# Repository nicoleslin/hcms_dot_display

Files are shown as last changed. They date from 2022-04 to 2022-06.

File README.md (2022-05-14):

# hcms_dot_display
repo for board files and drivers for hp hcms dot displays

## link dump
https://github.com/SpenceKonde/megaTinyCore/blob/master/megaavr/extras/ATtiny_x26.md
https://teddywarner.org/Projects/SerialUPDI/
https://github.com/SpenceKonde/AVR-Guidance/blob/master/UPDI/jtag2updi.md
http://ad7i.net/main/analysis-of-resistor-values-for-pymcuprog-usbusart-serial-programming/
https://www.mouser.com/ProductDetail/Apem/MHPS2283?qs=%2Fs1LKTamv0woxsbKv1Ncmw%3D%3D

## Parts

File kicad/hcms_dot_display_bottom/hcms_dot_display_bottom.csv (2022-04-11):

Source: | C:\Users\nslni\Documents\projects\dot_display\hcms_dot_display\kicad\hcms_dot_display\hcms_dot_display.kicad_sch
Date: | 04/10/2022 08:59:22
Tool: | Eeschema (6.0.2)
Generator: | C:\Users\nslni\Documents\KiCad\6.0\scripting\plugins/bom_csv_grouped_by_value_with_fp_and_mpn.py
Component Count: | 52
Ref | Qnty | Value | Cmp name | Footprint | Description | Vendor | MPN
C1, C9, C10, C11, | 4 | 10nF | C_Small | Capacitor_SMD:C_0603_1608Metric | Unpolarized capacitor, small symbol
C2, C3, C6, C8, C12, | 5 | 100nF | C_Small | Capacitor_SMD:C_0603_1608Metric | Unpolarized capacitor, small symbol
C4, C5, | 2 | 47pF | C_Small | Capacitor_SMD:C_0603_1608Metric | Unpolarized capacitor, small symbol
C7, | 1 | 4.7uF | C_Small | Capacitor_SMD:C_0603_1608Metric | Unpolarized capacitor, small symbol
D1, | 1 | HCMS-272X | HCMS-272X | hcms:HCMS-2722 |  |  | HCMS-2722
J1, J3, | 2 | Conn_01x12 | Conn_01x12 | hcms:board to board con top bot | Generic connector, single row, 01x12, script generated (kicad-library-utils/schlib/autogen/connector/)
J2, | 1 | USB_C_Receptacle_USB2.0 | USB_C_Receptacle_USB2.0 | hcms:213716-0001 | USB 2.0-only Type-C Receptacle connector |  | 213716-0001
J4, | 1 | Conn_01x11_Female | Conn_01x11_Female | Connector_PinSocket_2.54mm:PinSocket_1x11_P2.54mm_Vertical | Generic connector, single row, 01x11, script generated (kicad-library-utils/schlib/autogen/connector/)
J5, | 1 | Conn_01x11_Male | Conn_01x11_Male | Connector_PinHeader_2.54mm:PinHeader_1x11_P2.54mm_Vertical | Generic connector, single row, 01x11, script generated (kicad-library-utils/schlib/autogen/connector/)
J6, J7, | 2 | Conn_01x12 | Conn_01x12 | hcms:board to board con left right | Generic connector, single row, 01x12, script generated (kicad-library-utils/schlib/autogen/connector/)
Q1, Q2, Q3, Q4, Q5, | 5 | Q_PMOS_DSG | Q_PMOS_DSG | Package_TO_SOT_SMD:SOT-23 | P-MOSFET transistor, drain/source/gate |  | DMP3099L-13
Q6, | 1 | Q_PMOS_DSG | SI4425FDY | Package_SO:SO-8_5.3x6.2mm_P1.27mm | P-Channel 30 V 12.7A (Ta), 18.3A (Tc) 2.3W (Ta), 4.8W (Tc) Surface Mount 8-SOIC |  | SI4425FDY-T1-GE3
R1, R6, R21, R22, | 4 | 0 | R | Resistor_SMD:R_0603_1608Metric | Resistor
R2, R7, R16, R17, | 4 | DNP | R | Resistor_SMD:R_0603_1608Metric | Resistor
R3, R10, R11, R12, R13, R14, | 6 | 200 | R | Resistor_SMD:R_0603_1608Metric | Resistor
R4, R5, | 2 | 5.1k | R | Resistor_SMD:R_0603_1608Metric | Resistor
R8, R9, | 2 | 27 | R | Resistor_SMD:R_0603_1608Metric | Resistor
R15, | 1 | 1k | R | Resistor_SMD:R_0603_1608Metric | Resistor
R18, R19, R20, | 3 | 10k | R | Resistor_SMD:R_0603_1608Metric | Resistor
RV1, | 1 | R_Potentiometer | R_Potentiometer | hcms:TRIM_3352T-1-201LF | Potentiometer |  | 3352T-1-503LF
SW1, | 1 | SW_DIP_x03 | SW_DIP_x03 | hcms:BPA03SB | 3x DIP Switch, Single Pole Single Throw (SPST) switch, small symbol |  | BPA03SB
U1, | 1 | ATtiny826-SXX | ATtiny826-SXX | Package_SO:SOIC-20W_7.5x12.8mm_P1.27mm | 20MHz, 8kB Flash, 512B SRAM, 512B EEPROM, debugWIRE, SOIC-20 |  | ATTINY826-SFR
U2, | 1 | FT231XS | FT231XS | Package_SO:SSOP-20_3.9x8.7mm_P0.635mm | Full Speed USB to Full Handshake UART, SSOP-20 |  | FT231XS-U

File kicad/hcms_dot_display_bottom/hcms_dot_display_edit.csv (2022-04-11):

Source: | C:\Users\nslni\Documents\projects\dot_display\hcms_dot_display\kicad\hcms_dot_display\hcms_dot_display.kicad_sch
Date: | 04/10/2022 08:59:22
Tool: | Eeschema (6.0.2)
Generator: | C:\Users\nslni\Documents\KiCad\6.0\scripting\plugins/bom_csv_grouped_by_value_with_fp_and_mpn.py
Component Count: | 52
baselining qty for 5 control boards (3 yield + attrition), 10 display boards (6 yield + attrition + min price break)
passives for 15 boards
Ref | Qnty | Value | Cmp name | Footprint | Description | Vendor | MPN | deviation | Qty in cart
C1, C9, C10, C11, | 4 | 10nF | C_Small | Capacitor_SMD:C_0603_1608Metric | Unpolarized capacitor, small symbol |  | 06033C103JAT4A |  | 60
C2, C3, C6, C8, C12, | 5 | 100nF | C_Small | Capacitor_SMD:C_0603_1608Metric | Unpolarized capacitor, small symbol |  | C0603C104K3RAC7081 |  | 100
C4, C5, | 2 | 47pF | C_Small | Capacitor_SMD:C_0603_1608Metric | Unpolarized capacitor, small symbol |  | 06033C470KAT2A |  | 50
C7, | 1 | 4.7uF | C_Small | Capacitor_SMD:C_0603_1608Metric | Unpolarized capacitor, small symbol |  | GRM188C71C475KE21D |  | 15
D1, | 1 | HCMS-272X | HCMS-272X | hcms:HCMS-2722 |  |  | HCMS-2722 |  | N/A
J1, J3, | 2 | Conn_01x12 | Conn_01x12 | hcms:board to board con top bot | Generic connector, single row, 01x12, script generated (kicad-library-utils/schlib/autogen/connector/) |  |  |  | N/A
J2, | 1 | USB_C_Receptacle_USB2.0 | USB_C_Receptacle_USB2.0 | hcms:213716-0001 | USB 2.0-only Type-C Receptacle connector |  | 213716-0001
J4, | 1 | Conn_01x11_Female | Conn_01x11_Female | Connector_PinSocket_2.54mm:PinSocket_1x11_P2.54mm_Vertical | Generic connector, single row, 01x11, script generated (kicad-library-utils/schlib/autogen/connector/) |  | SMC-1-11-1-GT |  | 5
J5, | 1 | Conn_01x11_Male | Conn_01x11_Male | Connector_PinHeader_2.54mm:PinHeader_1x11_P2.54mm_Vertical | Generic connector, single row, 01x11, script generated (kicad-library-utils/schlib/autogen/connector/) |  | PH1-11-UA |  | 10
J6, J7, | 2 | Conn_01x12 | Conn_01x12 | hcms:board to board con left right | Generic connector, single row, 01x12, script generated (kicad-library-utils/schlib/autogen/connector/) |  |  |  | N/A
Q1, Q2, Q3, Q4, Q5, | 5 | Q_PMOS_DSG | Q_PMOS_DSG | Package_TO_SOT_SMD:SOT-23 | P-MOSFET transistor, drain/source/gate |  | DMP3099L-13 | PJA3411_R1_00001 | 50
Q6, | 1 | Q_PMOS_DSG | SI4425FDY | Package_SO:SO-8_5.3x6.2mm_P1.27mm | P-Channel 30 V 12.7A (Ta), 18.3A (Tc) 2.3W (Ta), 4.8W (Tc) Surface Mount 8-SOIC |  | SI4425FDY-T1-GE3 |  | 5
R1, R6, R21, R22, | 4 | 0 | R | Resistor_SMD:R_0603_1608Metric | Resistor |  | AC0603JR-070RL |  | 100
R2, R7, R16, R17, | 4 | DNP | R | Resistor_SMD:R_0603_1608Metric | Resistor |  |  |  | N/A
R3, R10, R11, R12, R13, R14, | 6 | 200 | R | Resistor_SMD:R_0603_1608Metric | Resistor |  | RNCP0603FTD200R |  | 100
R4, R5, | 2 | 5.1k | R | Resistor_SMD:R_0603_1608Metric | Resistor |  | RMCF0603FT5K10 |  | 30
R8, R9, | 2 | 27 | R | Resistor_SMD:R_0603_1608Metric | Resistor |  | RMCF0603FT27R0 |  | 30
R15, | 1 | 1k | R | Resistor_SMD:R_0603_1608Metric | Resistor |  | RMCF0603FT1K00 |  | 15
R18, R19, R20, | 3 | 10k | R | Resistor_SMD:R_0603_1608Metric | Resistor |  | RMCF0603FT10K0 |  | 100
RV1, | 1 | R_Potentiometer | R_Potentiometer | hcms:TRIM_3352T-1-201LF | Potentiometer |  | 3352T-1-503LF |  | 5
SW1, | 1 | SW_DIP_x03 | SW_DIP_x03 | hcms:BPA03SB | 3x DIP Switch, Single Pole Single Throw (SPST) switch, small symbol |  | BPA03SB |  | 5
U1, | 1 | ATtiny826-SXX | ATtiny826-SXX | Package_SO:SOIC-20W_7.5x12.8mm_P1.27mm | 20MHz, 8kB Flash, 512B SRAM, 512B EEPROM, debugWIRE, SOIC-20 |  | ATTINY826-SFR | ATTINY826-SF | 10
U2, | 1 | FT231XS | FT231XS | Package_SO:SSOP-20_3.9x8.7mm_P0.635mm | Full Speed USB to Full Handshake UART, SSOP-20 |  | FT231XS-U |  | 5

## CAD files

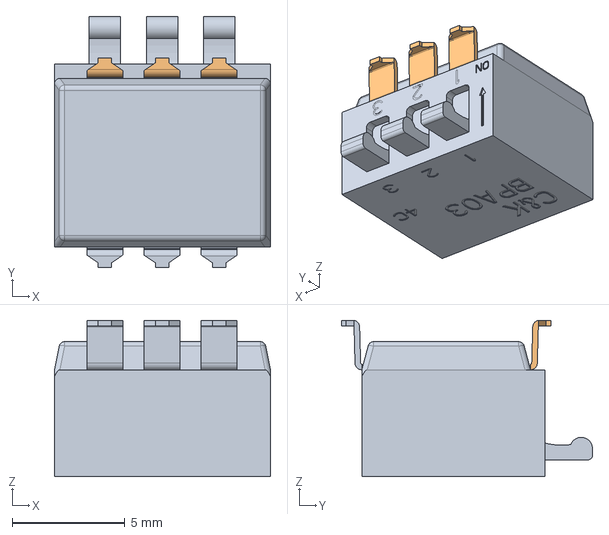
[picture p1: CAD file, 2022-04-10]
step/BPA03SB.stp
9.60 x 11.1 x 6.95 mm

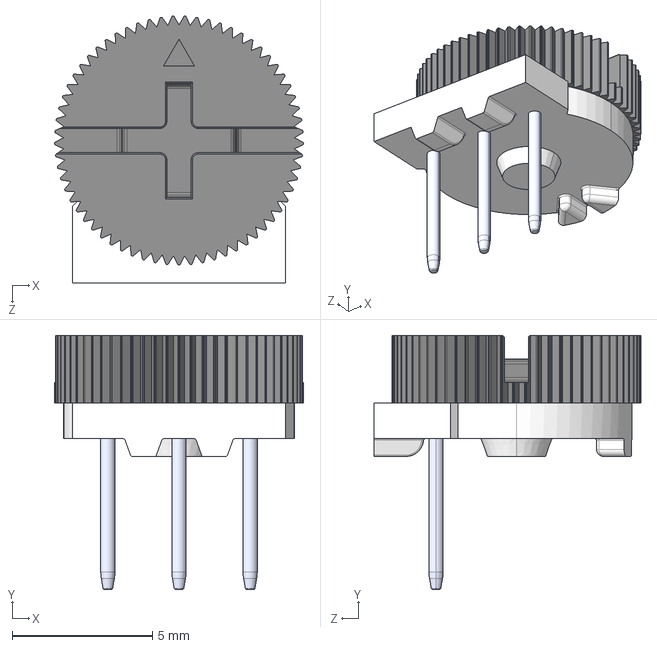
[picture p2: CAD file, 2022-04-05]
step/TRIM_3352T-1-201LF.step
8.89 x 9.07 x 9.52 mm

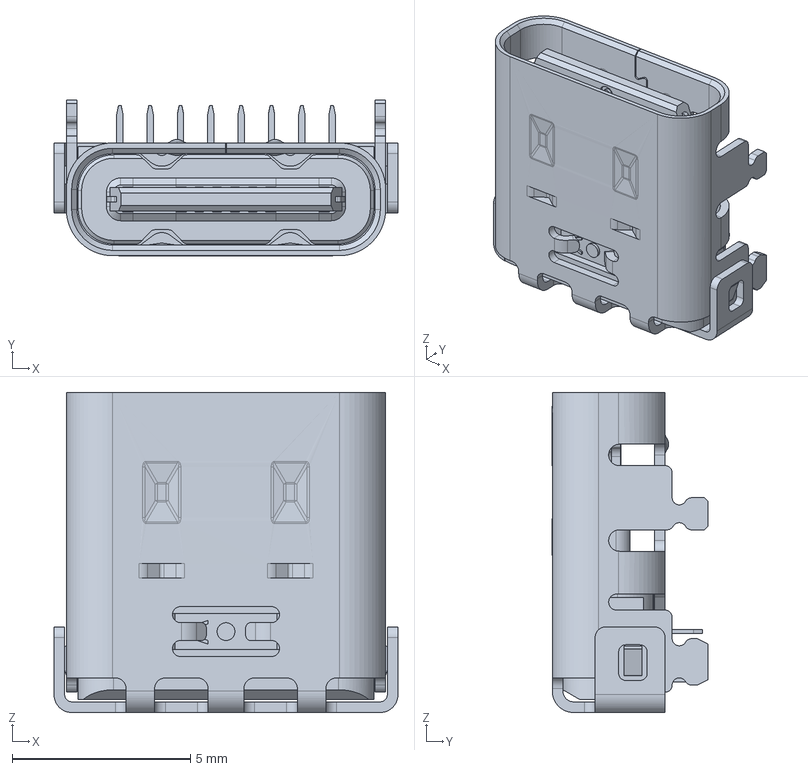
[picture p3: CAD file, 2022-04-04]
step/2137160001.stp
9.64 x 4.36 x 8.97 mm

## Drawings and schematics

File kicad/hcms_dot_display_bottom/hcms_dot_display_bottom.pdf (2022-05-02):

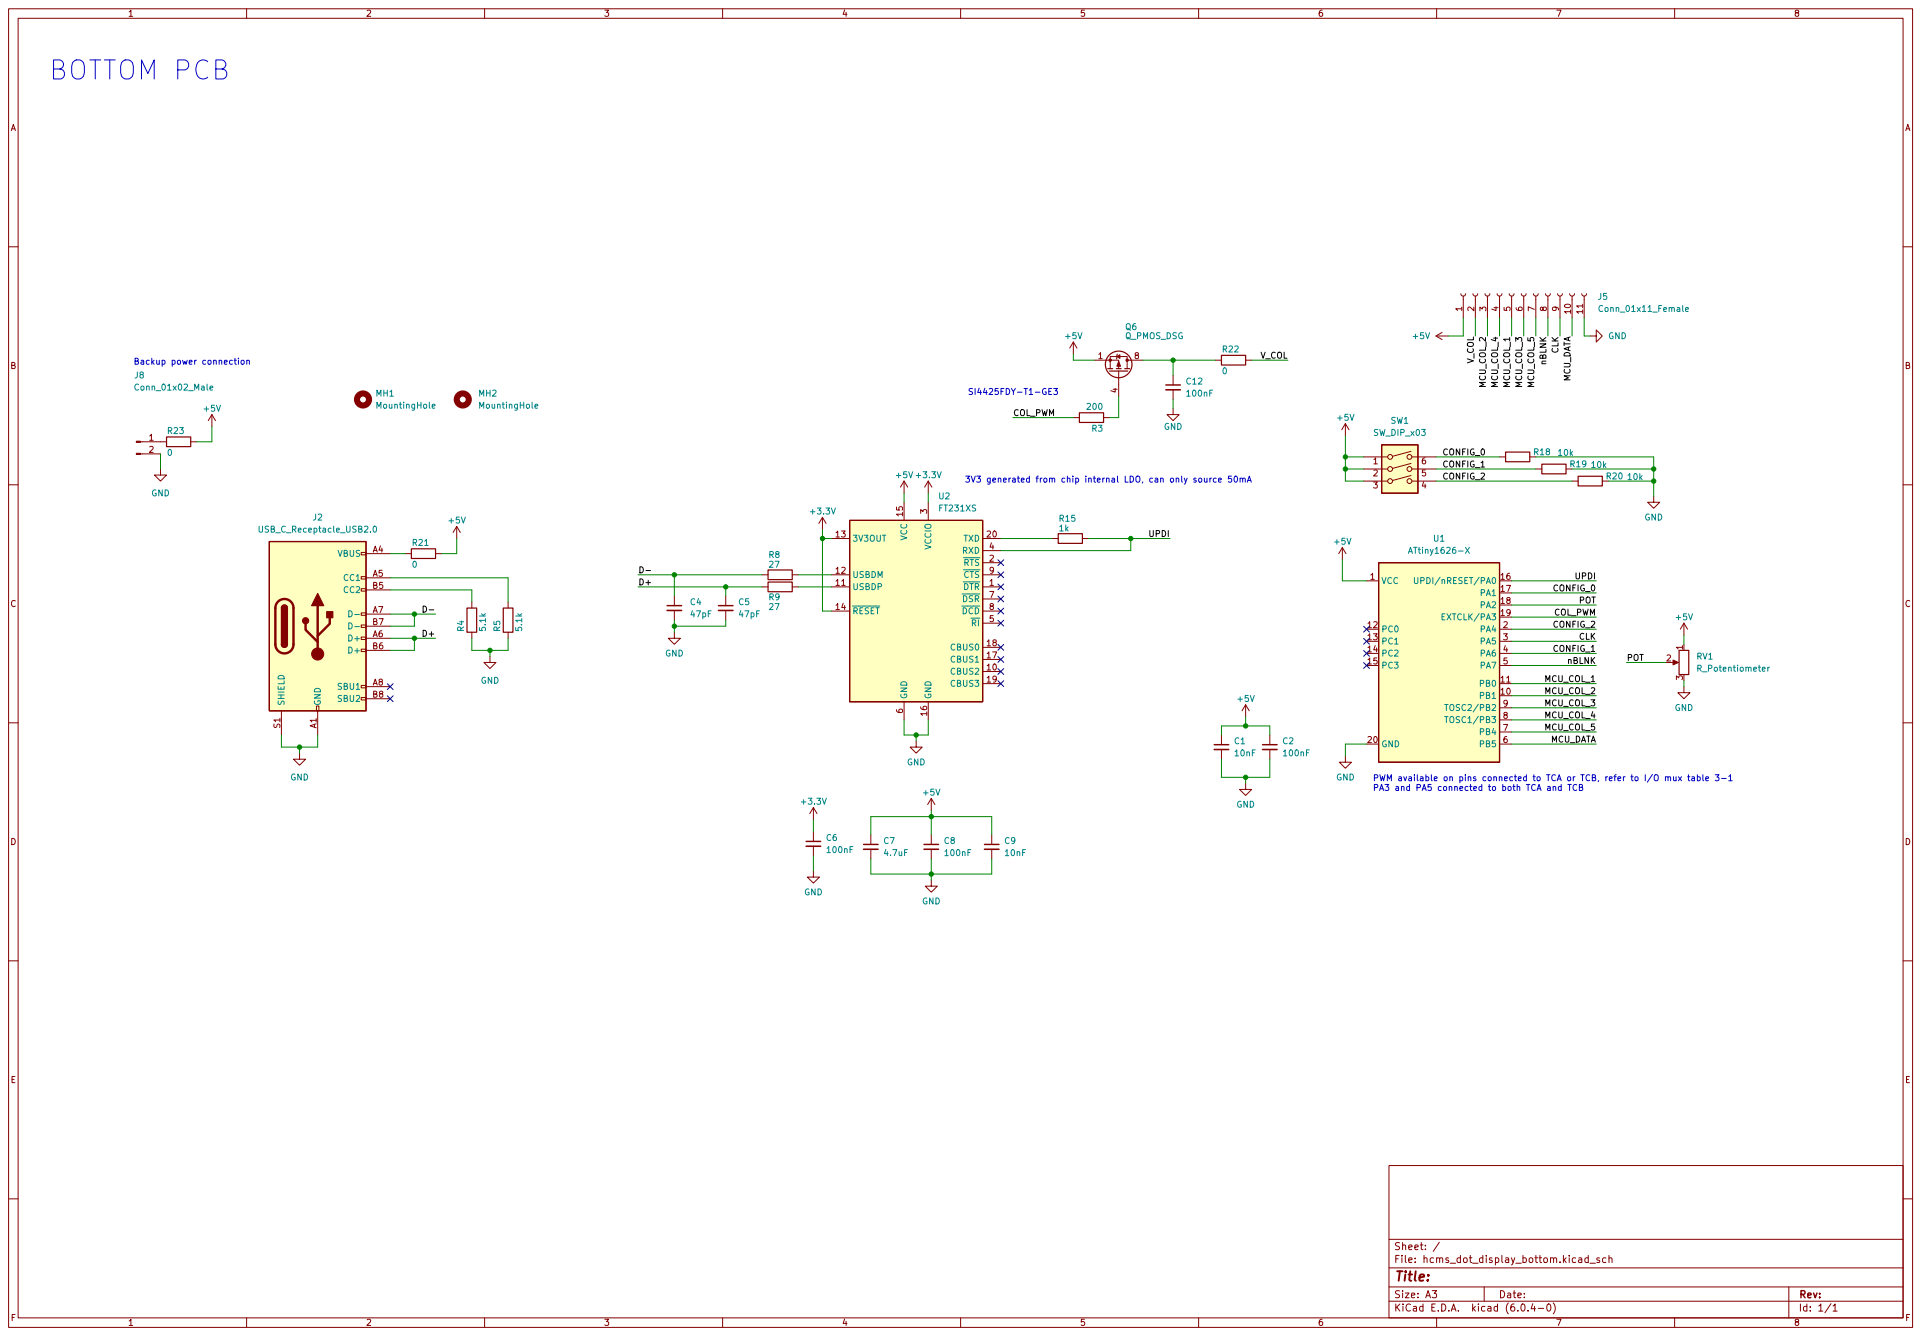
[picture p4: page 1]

6 ~{DSR} 7 ~{DCD} 8 ~{CTS} 9 U2FT231XS GND GND MH2 MountingHole MH1 MountingHole +5V +3.3V R19 10k R20 10k R21

3V3 generated from chip internal LDO, can only source 50mA

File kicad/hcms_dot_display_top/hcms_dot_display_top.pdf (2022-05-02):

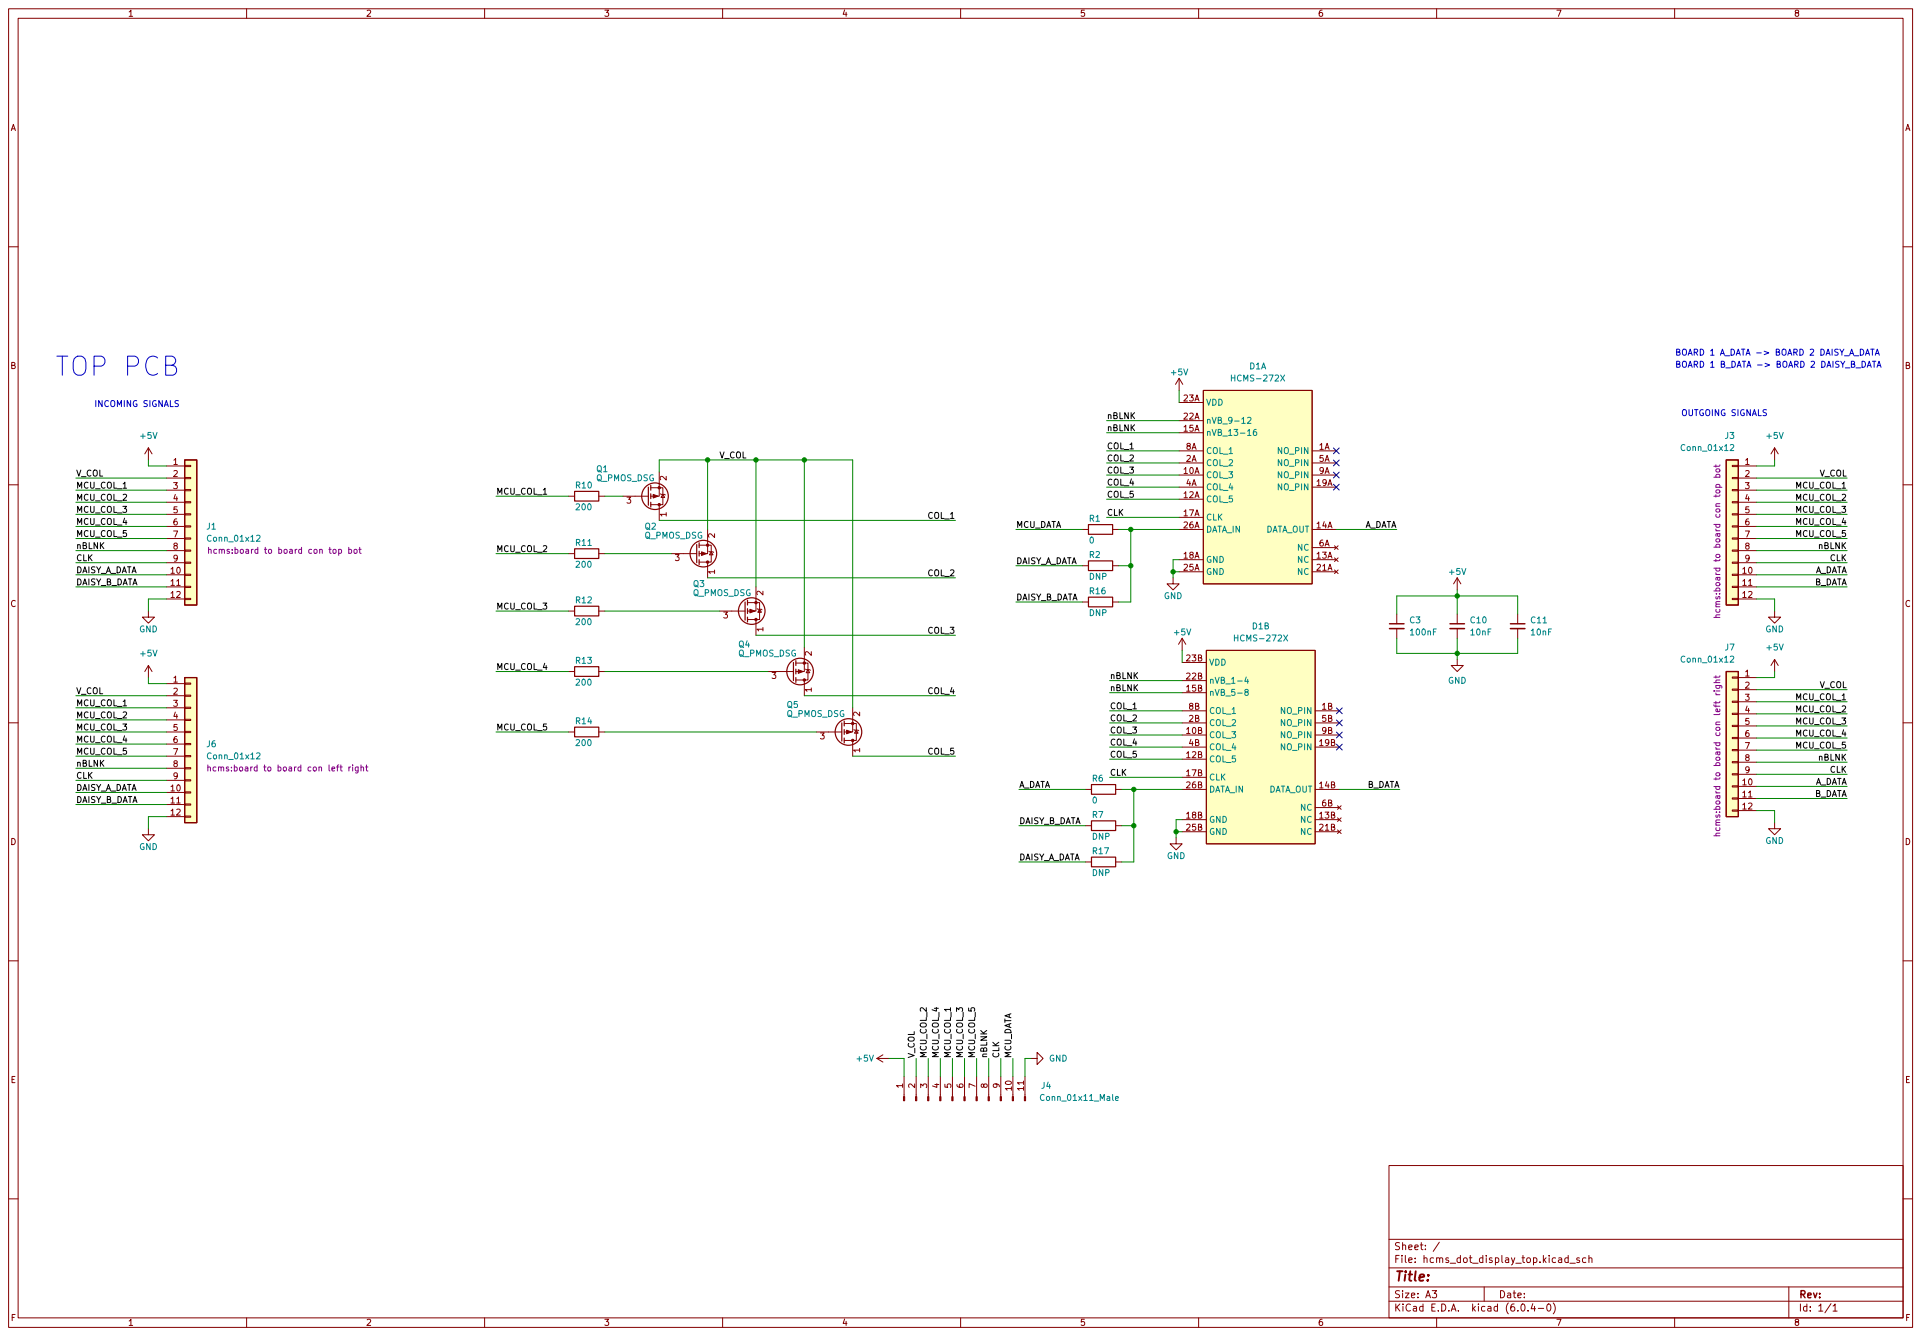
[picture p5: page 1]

INCOMING SIGNALS TOP PCB

hcms:board to board con left right GND

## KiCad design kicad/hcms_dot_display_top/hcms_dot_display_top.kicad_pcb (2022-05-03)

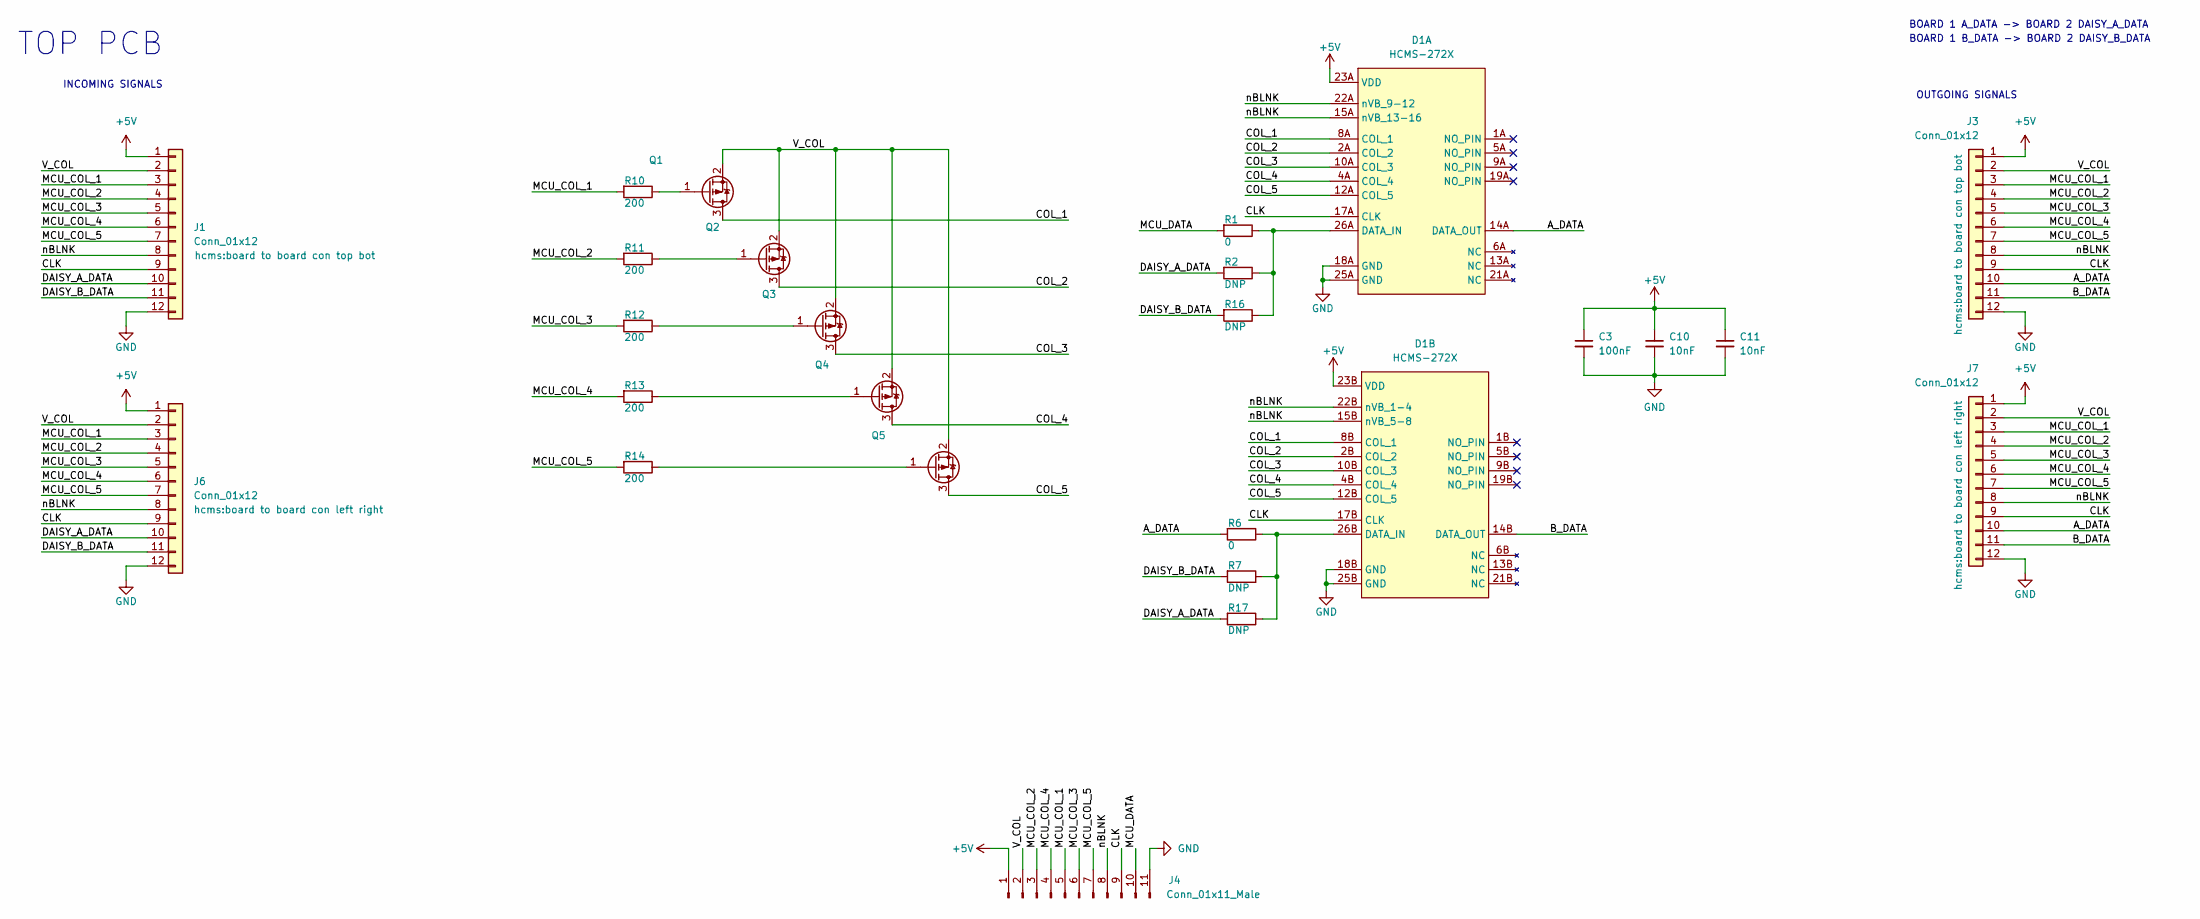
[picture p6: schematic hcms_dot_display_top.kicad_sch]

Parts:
C3: 100nF; C_0603_1608Metric
C10, C11: 10nF; C_0603_1608Metric
D1: HCMS-272X; HCMS-2722
J1, J3: Conn_01x12; board to board con top bot
J4: Conn_01x11_Male; PinHeader_1x11_P2.54mm_Vertical
J6, J7: Conn_01x12; board to board con left right
Q1, Q2, Q3, Q4, Q5: (no value)
R1, R6: 0; R_0603_1608Metric
R2, R7, R16, R17: DNP; R_0603_1608Metric
R10, R11, R12, R13, R14: 200; R_0603_1608Metric

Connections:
+5V: C3.1, C10.1, C11.1, D1.23A (VDD), D1.23B (VDD), J1.1, J3.1, J4.1, J6.1, J7.1
/A_DATA: D1.14A (DATA_OUT), J3.10, J7.10, R6.2
/B_DATA: D1.14B (DATA_OUT), J3.11, J7.11
/CLK: D1.17A (CLK), D1.17B (CLK), J1.9, J3.9, J4.9, J6.9, J7.9
/COL_1: D1.8A (COL_1), D1.8B (COL_1), Q1.3 (D)
/COL_2: D1.2A (COL_2), D1.2B (COL_2), Q2.3 (D)
/COL_3: D1.10A (COL_3), D1.10B (COL_3), Q3.3 (D)
/COL_4: D1.4A (COL_4), D1.4B (COL_4), Q4.3 (D)
/COL_5: D1.12A (COL_5), D1.12B (COL_5), Q5.3 (D)
/DAISY_A_DATA: J1.10, J6.10, R2.2, R17.2
/DAISY_B_DATA: J1.11, J6.11, R7.2, R16.2
/MCU_COL_1: J1.3, J3.3, J4.5, J6.3, J7.3, R10.2
/MCU_COL_2: J1.4, J3.4, J4.3, J6.4, J7.4, R11.2
/MCU_COL_3: J1.5, J3.5, J4.6, J6.5, J7.5, R12.2
/MCU_COL_4: J1.6, J3.6, J4.4, J6.6, J7.6, R13.2
/MCU_COL_5: J1.7, J3.7, J4.7, J6.7, J7.7, R14.2
/MCU_DATA: J4.10, R1.2
/V_COL: J1.2, J3.2, J4.2, J6.2, J7.2, Q1.2 (S), Q2.2 (S), Q3.2 (S), Q4.2 (S), Q5.2 (S)
/nBLNK: D1.15A (nVB_13-16), D1.15B (nVB_5-8), D1.22A (nVB_9-12), D1.22B (nVB_1-4), J1.8, J3.8, J4.8, J6.8, J7.8
GND: C3.2, C10.2, C11.2, D1.18A (GND), D1.18B (GND), D1.25A (GND), D1.25B (GND), J1.12, J3.12, J4.11, J6.12, J7.12
unnamed: D1.26A (DATA_IN), R1.1, R2.1, R16.1
unnamed: D1.26B (DATA_IN), R6.1, R7.1, R17.1
unnamed: Q1.1 (G), R10.1
unnamed: Q2.1 (G), R11.1
unnamed: Q3.1 (G), R12.1
unnamed: Q4.1 (G), R13.1
unnamed: Q5.1 (G), R14.1

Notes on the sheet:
BOARD 1 A_DATA -> BOARD 2 DAISY_A_DATA
BOARD 1 B_DATA -> BOARD 2 DAISY_B_DATA
INCOMING SIGNALS
OUTGOING SIGNALS
TOP PCB

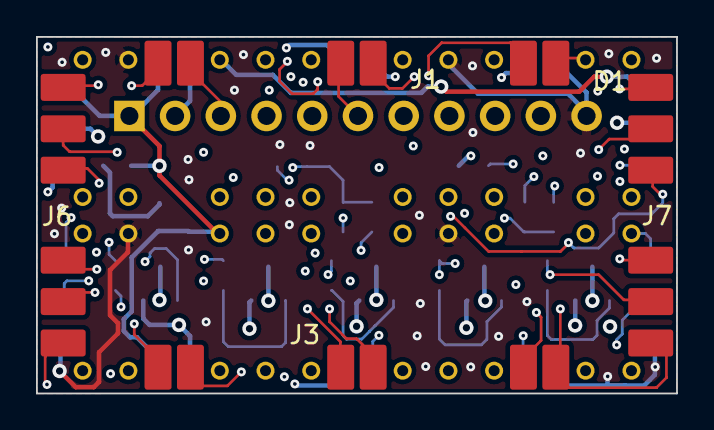
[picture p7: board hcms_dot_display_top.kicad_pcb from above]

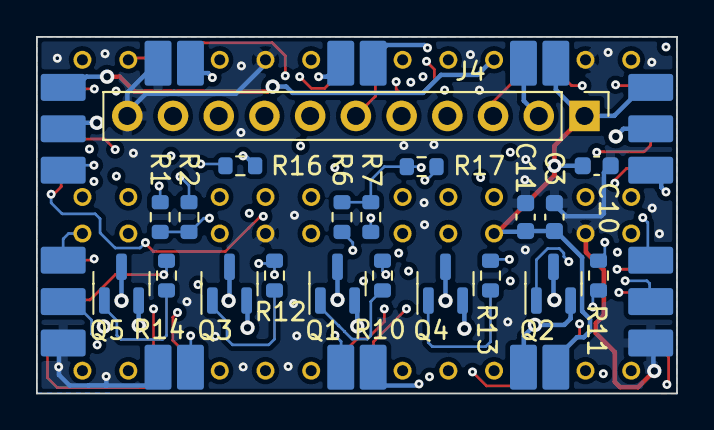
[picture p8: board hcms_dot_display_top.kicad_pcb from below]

Board: 4 copper layers, 35.6 x 19.8 mm, 25 parts (20 on the bottom side), 27 nets.

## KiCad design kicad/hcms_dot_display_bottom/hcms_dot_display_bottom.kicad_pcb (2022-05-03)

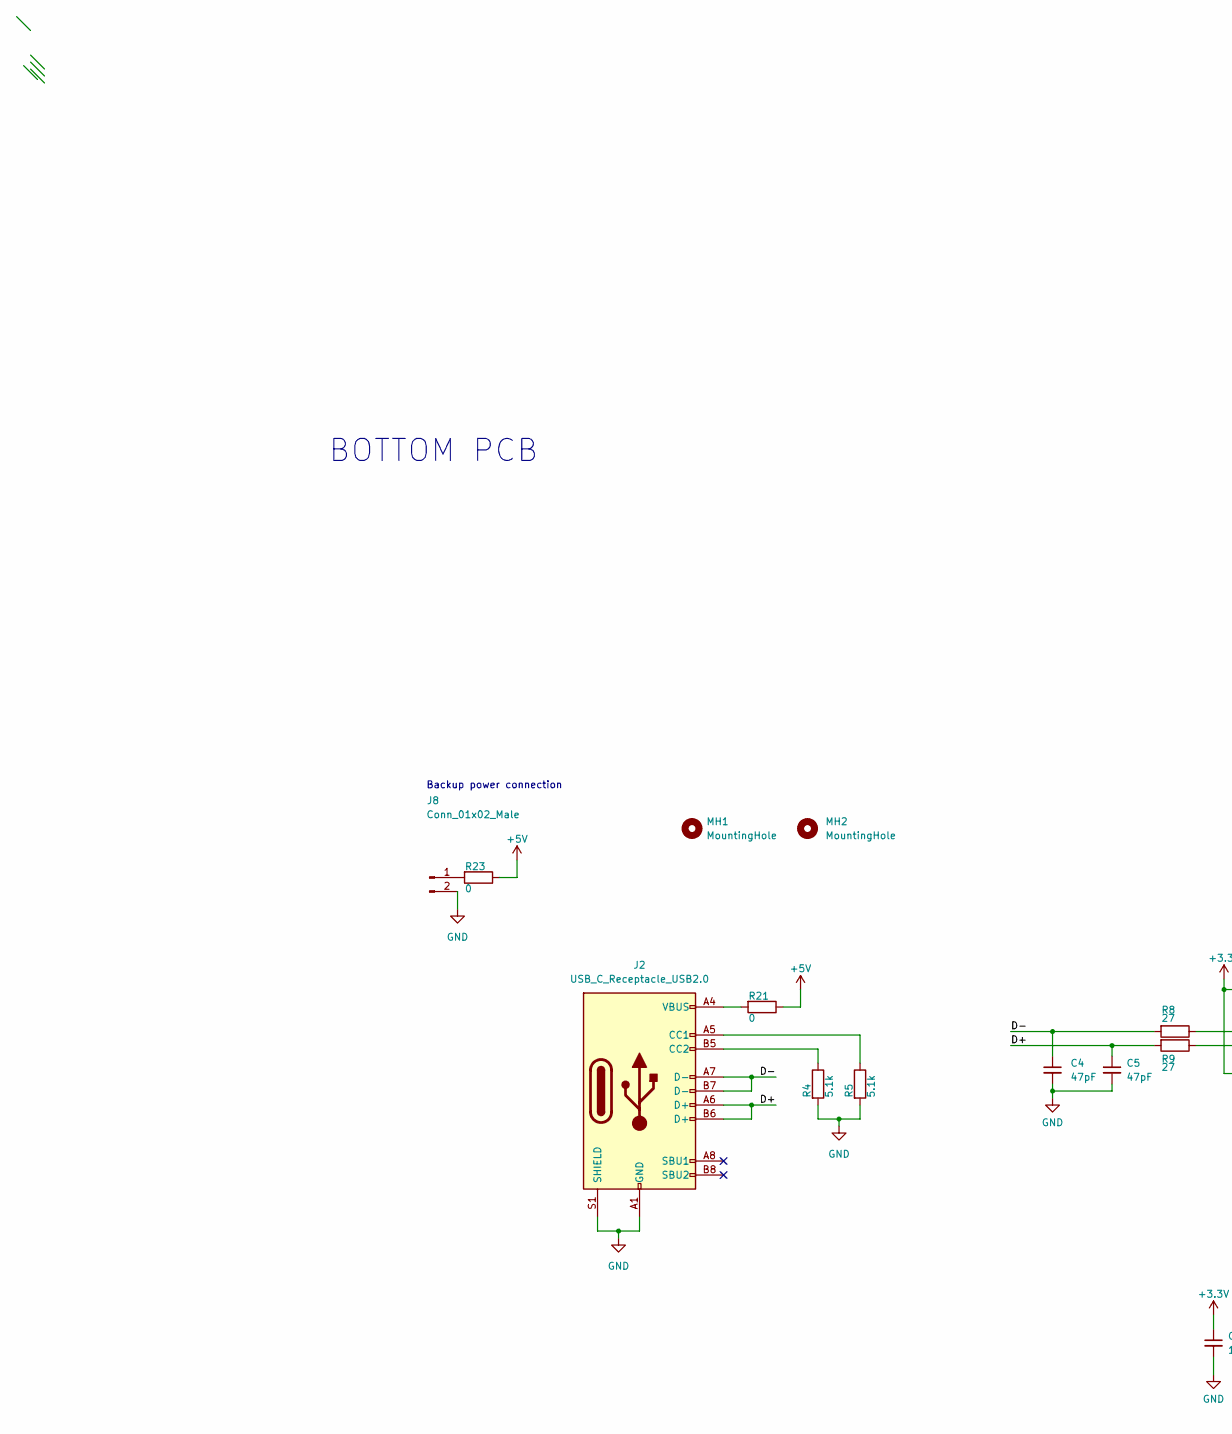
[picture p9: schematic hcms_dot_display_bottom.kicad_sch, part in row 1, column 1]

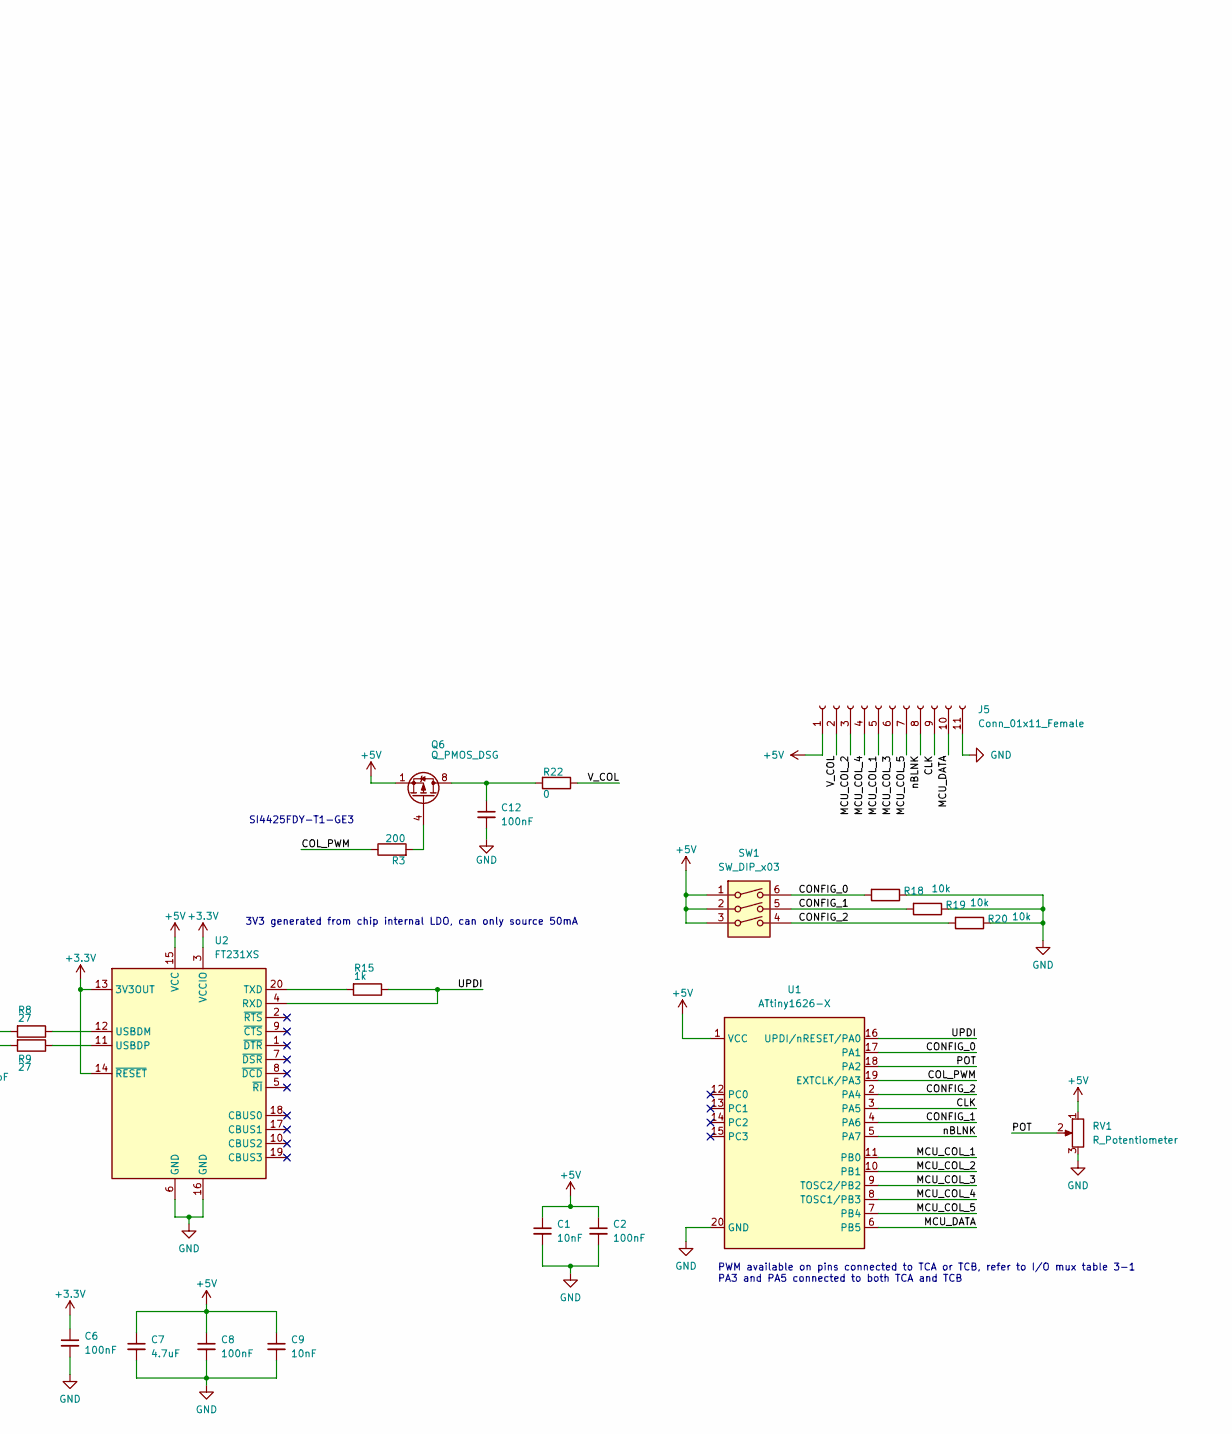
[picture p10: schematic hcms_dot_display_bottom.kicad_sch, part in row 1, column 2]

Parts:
C1, C9: 10nF; C_0603_1608Metric
C2, C6, C8, C12: 100nF; C_0603_1608Metric
C4, C5: 47pF; C_0603_1608Metric
C7: 4.7uF; C_0603_1608Metric
J2: USB_C_Receptacle_USB2.0; 213716-0001
J5: Conn_01x11_Female; PinSocket_1x11_P2.54mm_Vertical
J8: Conn_01x02_Male; PinHeader_1x02_P2.54mm_Vertical
MH1, MH2: MountingHole; MountingHole_2.2mm_M2_Pad_Via
Q6: Q_PMOS_DSG; SO-8_5.3x6.2mm_P1.27mm
R3: 200; R_0603_1608Metric
R4, R5: 5.1k; R_0603_1608Metric
R8, R9: 27; R_0603_1608Metric
R15: 1k; R_0603_1608Metric
R18, R19, R20: 10k; R_0603_1608Metric
R21, R22, R23: 0; R_0603_1608Metric
RV1: R_Potentiometer; TRIM_3352T-1-201LF
SW1: SW_DIP_x03; BPA03SB
U1: ATtiny1626-X; SSOP-20_5.3x7.2mm_P0.65mm
U2: FT231XS; SSOP-20_3.9x8.7mm_P0.635mm

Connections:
+3V3: C6.1, U2.3 (VCCIO), U2.13 (3V3OUT), U2.14 (~RESET)
+5V: C1.1, C2.1, C7.1, C8.1, C9.1, J5.1, Q6.1 (S), Q6.2 (S), Q6.3 (S), R21.1, R23.1, RV1.1, SW1.1, SW1.2, SW1.3, U1.1 (VCC), U2.15 (VCC)
/CLK: J5.9, U1.3 (PA5)
/COL_PWM: R3.1, U1.19 (EXTCLK/PA3)
/CONFIG_0: R18.2, SW1.6, U1.17 (PA1)
/CONFIG_1: R19.2, SW1.5, U1.4 (PA6)
/CONFIG_2: R20.2, SW1.4, U1.2 (PA4)
/D+: C5.1, J2.A6 (D+), J2.B6 (D+), R9.2
/D-: C4.1, J2.A7 (D-), J2.B7 (D-), R8.2
/MCU_COL_1: J5.5, U1.11 (PB0)
/MCU_COL_2: J5.3, U1.10 (PB1)
/MCU_COL_3: J5.6, U1.9 (TOSC2/PB2)
/MCU_COL_4: J5.4, U1.8 (TOSC1/PB3)
/MCU_COL_5: J5.7, U1.7 (PB4)
/MCU_DATA: J5.10, U1.6 (PB5)
/POT: RV1.2, U1.18 (PA2)
/UPDI: R15.1, U1.16 (UPDI/nRESET/PA0), U2.4 (RXD)
/V_COL: J5.2, R22.1
/nBLNK: J5.8, U1.5 (PA7)
GND: C1.2, C2.2, C4.2, C5.2, C6.2, C7.2, C8.2, C9.2, C12.2, J2.A1 (GND), J2.A12 (GND), J2.B1 (GND), J2.B12 (GND), J2.S1 (SHIELD), J5.11, J8.2, R4.2, R5.2, R18.1, R19.1, R20.1, RV1.3, U1.20 (GND), U2.6 (GND), U2.16 (GND)
unnamed: C12.1, Q6.5 (D), Q6.6 (D), Q6.7 (D), Q6.8 (D), R22.2
unnamed: J2.A4 (VBUS), J2.A9 (VBUS), J2.B4 (VBUS), J2.B9 (VBUS), R21.2
unnamed: J2.A5 (CC1), R5.1
unnamed: J2.B5 (CC2), R4.1
unnamed: J8.1, R23.2
unnamed: Q6.4 (G), R3.2
unnamed: R8.1, U2.12 (USBDM)
unnamed: R9.1, U2.11 (USBDP)
unnamed: R15.2, U2.20 (TXD)

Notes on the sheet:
BOTTOM PCB
3V3 generated from chip internal LDO, can only source 50mA
PWM available on pins connected to TCA or TCB, refer to I/O mux table 3-1 PA3 and PA5 connected to both TCA and TCB
SI4425FDY-T1-GE3
Backup power connection

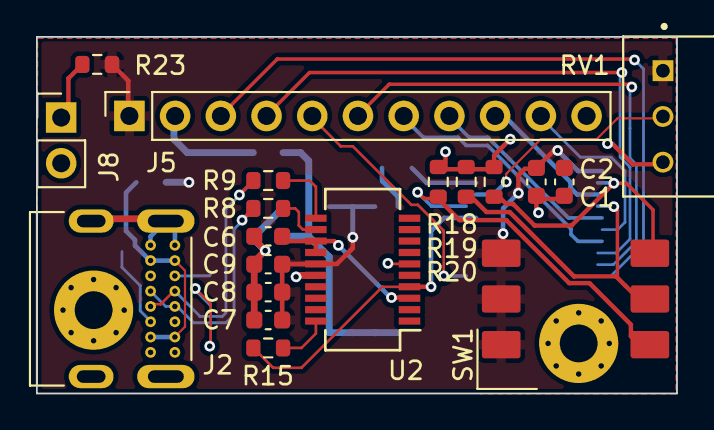
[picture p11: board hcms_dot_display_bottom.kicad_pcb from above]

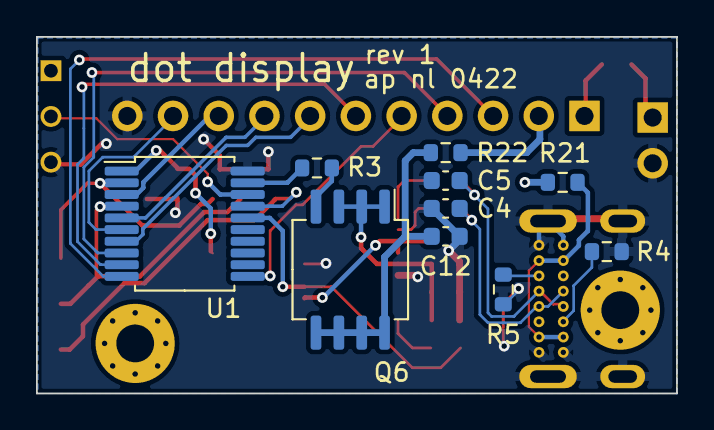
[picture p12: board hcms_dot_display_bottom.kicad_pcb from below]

Board: 2 copper layers, 35.6 x 19.8 mm, 31 parts (12 on the bottom side), 29 nets.

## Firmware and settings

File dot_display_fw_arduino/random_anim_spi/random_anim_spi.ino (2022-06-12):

#include <Arduino.h>
#include <SPI.h>

#define SW_CONFIG_0_PIN 14 // PA1
#define SW_CONFIG_1_PIN 2  // PA6
#define SW_CONFIG_2_PIN 0  // PA4
#define POT_PIN         15 // PA2
// #define CLK_PIN         1  // PA5

// #define COL_PWM_PIN     16 // PA3
#define COL_PWM_PIN     1  // PA5
#define nBLNK_PIN       3  // PA7
#define MCU_COL_1_PIN   9  // PB0
#define MCU_COL_2_PIN   8  // PB1
#define MCU_COL_3_PIN   7  // PB2
#define MCU_COL_4_PIN   6  // PB3
#define MCU_COL_5_PIN   5  // PB4
#define MCU_DATA_PIN    4  // PB5

#define NUM_COL 5
#define NUM_ROW 7
#define NUM_CHAR 16

#define RANDOM_OUT_OF 3000
#define PROBABILITY_ON 10 // out of RANDOM_OUT_OF

uint8_t pot_val = 0;
uint8_t blink_val = 0;
unsigned long pot_start_time = 0;

unsigned long col_start_time = 0;
short col_pin_array[5] = {MCU_COL_1_PIN, MCU_COL_2_PIN, MCU_COL_3_PIN, MCU_COL_4_PIN, MCU_COL_5_PIN};
uint16_t num_row_bits = NUM_ROW * NUM_CHAR;
short data_bit = 0;

uint8_t dot_matrix[NUM_CHAR][NUM_ROW][NUM_COL] = {0};
uint8_t spi_byte = 0;
uint8_t spi_counter = 0;
uint8_t first_spi_byte = 1;
uint8_t num_dummy_bits = 0;

typedef struct {
  uint8_t counter;
  uint8_t counter_end;
  uint8_t counter_level;
} dot_t;

void display_rand() {
  spi_counter = num_dummy_bits;
  first_spi_byte = 1;
  int rand_bit;

  for(int i = 0; i < num_row_bits; i++) {
    rand_bit = random(0, 2);
    if (first_spi_byte && (spi_counter < 8)) {
      spi_byte = spi_byte | (rand_bit << spi_counter);
      spi_counter = spi_counter + 1;
    }

    else if (first_spi_byte && !(spi_counter < 8)) {
      first_spi_byte = 0;
      
      // send SPI transfer
      SPI.transfer(spi_byte);
      spi_counter = 0;
      spi_byte = 0;
    }

    // not first_spi_byte, must be doing standard spi
    else if (!first_spi_byte && (spi_counter < 8)) {
      spi_byte = spi_byte | (rand_bit << spi_counter);
      spi_counter = spi_counter + 1;
    }

    else {
      // send SPI transfer
      SPI.transfer(spi_byte);
      spi_counter = 0;
      spi_byte = 0;
    }
  }
}

void display_all_ones() {
  spi_counter = num_dummy_bits;
  first_spi_byte = 1;

  for(int i = 0; i < num_row_bits; i++) {
    if (first_spi_byte && (spi_counter < 8)) {
      spi_byte = spi_byte | (1 << spi_counter);
      spi_counter = spi_counter + 1;
    }

    else if (first_spi_byte && !(spi_counter < 8)) {
      first_spi_byte = 0;
      
      // send SPI transfer
      SPI.transfer(spi_byte);
      spi_counter = 0;
      spi_byte = 0;
    }

    // not first_spi_byte, must be doing standard spi
    else if (!first_spi_byte && (spi_counter < 8)) {
      spi_byte = spi_byte | (1 << spi_counter);
      spi_counter = spi_counter + 1;
    }

    else {
      // send SPI transfer
      SPI.transfer(spi_byte);
      spi_counter = 0;
      spi_byte = 0;
    }
  }
  
}

//void reset_display(){
//  for(int i = 0; i < num_row_bits; i++) {
//    digitalWrite(CLK_PIN, HIGH);
//    digitalWrite(MCU_DATA_PIN, LOW);
//    digitalWrite(CLK_PIN, LOW);
//  }
//}

//void write_dot(int level){
//  digitalWrite(CLK_PIN, HIGH);
//  digitalWrite(MCU_DATA_PIN, level);
//  digitalWrite(CLK_PIN, LOW);
//}

/***
void display_chars(uint8_t char_matrix[NUM_CHAR][NUM_ROW][NUM_COL]){
  spi_counter = num_dummy_bits;
  first_spi_byte = 1;
  
  for(int i = 0; i < NUM_COL; i++)
  {
    for(int j = NUM_CHAR; j > 0; j--) 
    {
      for(int k = 0; k < NUM_ROW; k++)
      {
        if (first_spi_byte && (spi_counter < 8)) {

          spi_counter = spi_counter + 1;
        }

        else if (first_spi_byte && !(spi_counter < 8)) {
          first_spi_byte = 0;
          spi_counter = 0;

          // send SPI transfer
        }

        // not first_spi_byte, must be doing standard spi
        else if () {
          
        else 
        }

        // check if dot is on
        
        // if dot is not on, use random() to determine if dot should turn on
          // dot should turn on
            // change dot_level to 

          // dot should stay off

        // if dot is on, check if counter has reached its max
          // counter not at max
            // increment dot_counter by 1, call write_dot(1)

          // counter at max
            // change dot_level to 0, change dot_counter to 0, call write_dot(0)

        
      }
    }
    
    digitalWrite(col_pin_array[i], LOW);
    delayMicroseconds(blink_val);
    digitalWrite(col_pin_array[i], HIGH);
  }
}
***/

void setup() {
  // put your setup code here, to run once:
  // Serial.begin(9600);
  // pinMode(SW_CONFIG_0_PIN, INPUT);
  pinMode(SW_CONFIG_1_PIN, INPUT);
  pinMode(SW_CONFIG_2_PIN, INPUT);
  pinMode(POT_PIN, INPUT);
  // pinMode(CLK_PIN, OUTPUT);
  pinMode(COL_PWM_PIN, OUTPUT);
  pinMode(nBLNK_PIN, OUTPUT);
  pinMode(MCU_COL_1_PIN, OUTPUT);
  pinMode(MCU_COL_2_PIN, OUTPUT);
  pinMode(MCU_COL_3_PIN, OUTPUT);
  pinMode(MCU_COL_4_PIN, OUTPUT);
  pinMode(MCU_COL_5_PIN, OUTPUT);
  pinMode(MCU_DATA_PIN, OUTPUT);

  analogReadResolution(8);
  // since the COL_PWM FET is PMOS, the duty cycle is (1 - (3V3/5V))*255 = 86
  analogWrite(COL_PWM_PIN, 200);
  // digitalWrite(COL_PWM_PIN,LOW);

  // digitalWrite(CLK_PIN, HIGH);
  digitalWrite(nBLNK_PIN, HIGH);
  digitalWrite(MCU_COL_1_PIN, HIGH);
  digitalWrite(MCU_COL_2_PIN, HIGH);
  digitalWrite(MCU_COL_3_PIN, HIGH);
  digitalWrite(MCU_COL_4_PIN, HIGH);
  digitalWrite(MCU_COL_5_PIN, HIGH);

  randomSeed(analogRead(POT_PIN));

  // initialize SPI
  SPI.swap(0);
  SPI.begin();

  // determine number of dummy bits required to stuff for SPI transfers
  num_dummy_bits = num_row_bits % 8;
 
  // reset_display();
  // display_all_ones();
  display_rand();
}

void loop() {
  // need to meet timing to pulse each column at a minimum of 100Hz, refresh rate of 150Hz is 4ms
  // The row data for a given column (one 7 bit byte per character) is loaded (bit serial) into the on-board 28 (56) bit shift register with high to low transitions of the Clock input.
  // load all row data for col 1 (7 bits per character, 16 characters, 112 bits)
  // illuminate col 1
  // repeat for col 2-5

  // display_chars(dot_matrix);

  for (int i = 0; i < 5; i++){
    digitalWrite(col_pin_array[i], LOW);
    delayMicroseconds(50);
    digitalWrite(col_pin_array[i], HIGH);
  }
  delayMicroseconds(1000);
  
}

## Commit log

2022-03-27 initial kicad commit
    [hcms_dot_display.kicad_pcb, hcms_dot_display.kicad_sch]
2022-03-30 progress from 0329
    [hcms_dot_display.kicad_sch]
2022-03-31 battery dying
    [hcms_dot_display.kicad_sch]
2022-04-01 Reduce number of FETs, cleaned up schematic added some footprints, and starting routing
    [hcms_dot_display.kicad_pcb, hcms_dot_display.kicad_sch]
2022-04-02 Added PNs for push button and pot with basic footprints, updated some resistor values
    [hcms_dot_display.kicad_pcb, hcms_dot_display.kicad_sch]
2022-04-02 slight mods to UPDI circuits
    [hcms_dot_display.kicad_sch]
2022-04-02 Updated dot matrix footprint, experimented with stacked control board design
    [MCU.kicad_sch, hcms_dot_display.kicad_pcb, hcms_dot_display.kicad_sch]
2022-04-02 Cleaned up layout strat
    [hcms_dot_display.kicad_pcb, hcms_dot_display.kicad_sch]
2022-04-03 fixed pot footprint, updated layout from schematics, changed board to board conn sch sym from 13 pin to 11 pin, reorgd sch sym to reflect stacked board design, added decoupling caps to top board
    [hcms_dot_display.kicad_pcb, hcms_dot_display.kicad_sch]
2022-04-04 fixed some footprints and edited placement
    [2137160001.stp, hcms_dot_display.csv, hcms_dot_display.kicad_pcb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]
2022-04-05 3d model environment variables lol
    [TRIM_3352T-1-201LF.step, hcms_dot_display.kicad_pcb]
2022-04-07 progress from 0406
    [hcms_dot_display.kicad_sch]
2022-04-08 updated micro to have more i/o
    [hcms_dot_display.kicad_sch]
2022-04-09 Added Vcol rail and switching PMOS. Started new board to board cons
    [hcms_dot_display.kicad_pcb, hcms_dot_display.kicad_sch]
2022-04-09 literally in the middle of fixing left right conn but time to climb
    [hcms_dot_display.kicad_sch]
2022-04-10 beginning of ecos
    [hcms_dot_display.kicad_pcb, hcms_dot_display.kicad_sch]
2022-04-10 aidan im pushing
    [BPA03SB.stp, hcms_dot_display.kicad_pcb, hcms_dot_display.kicad_sch]
2022-04-10 added switch fp, cleaned up placement. ready for routing
    [hcms_dot_display.kicad_pcb, hcms_dot_display.kicad_sch]
2022-04-10 finally gonna start routing ??
    [hcms_dot_display.kicad_pcb, hcms_dot_display.kicad_sch]
2022-04-10 Updated DRC rules to match JLCPCB guide
    [hcms_dot_display.kicad_pcb]
2022-04-10 I did a lot of routing lol
    [hcms_dot_display.kicad_pcb]
2022-04-10 moar route
    [hcms_dot_display.kicad_pcb]
2022-04-10 Finished first draft of display board routing
    [hcms_dot_display.kicad_pcb]
2022-04-10 Finished first draft of MCU board routing
    [hcms_dot_display.kicad_pcb]
2022-04-10 Fixed min angular ring DRC, increased via size t0 .2mm .5mm
    [hcms_dot_display.kicad_pcb]
2022-04-11 Fixed USB footprint to accomodate DRCs
    [hcms_dot_display.kicad_pcb, hcms_dot_display.kicad_sch]
2022-04-11 ready for layout review
    [hcms_dot_display.csv, hcms_dot_display.kicad_pcb, hcms_dot_display_edit.csv]
2022-04-16 layout ready for review i think
    [hcms_dot_display.kicad_pcb, hcms_dot_display.kicad_sch]
2022-04-16 aidan take the wheel
    [hcms_dot_display.kicad_pcb]
2022-04-16 splitting boards into 2 projects
    [MCU.kicad_sch, hcms_dot_display_bottom.csv, hcms_dot_display_bottom.kicad_pcb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]
2022-04-16 Top board refined
    [hcms_dot_display_top.kicad_pcb, hcms_dot_display_top.kicad_sch]
2022-04-16 progress making bottom manufacturable
    [hcms_dot_display_bottom.kicad_pcb, hcms_dot_display_bottom.kicad_sch]
2022-04-26 Updated DRCs and fixed connector edge clearance
    [hcms_dot_display_top.kicad_pcb]
2022-04-26 fuck ya
    [hcms_dot_display_bottom.kicad_pcb]
2022-04-26 easter eggs, actually ready for final review. boards passing DRC
    [hcms_dot_display_bottom.kicad_pcb, hcms_dot_display_top.kicad_pcb]
2022-04-26 checked DRC one more time
    [hcms_dot_display_top.kicad_pcb]
2022-05-01 edits to top
    [hcms_dot_display_top.kicad_pcb]
2022-05-02 Updated DMP footprint on bottom board and re routed
    [hcms_dot_display_top.kicad_pcb, hcms_dot_display_top.kicad_sch]
2022-05-02 changes to bottom
    [hcms_dot_display_bottom.kicad_pcb]
2022-05-03 ran DRC on top
    [hcms_dot_display_top.kicad_pcb]
2022-05-03 Fixed daisy issue left right
    [hcms_dot_display_top.kicad_pcb]
2022-05-03 bottom gerbers
    [hcms_dot_display_bottom-B_Cu.gbl, hcms_dot_display_bottom-B_Mask.gbs, hcms_dot_display_bottom-B_Paste.gbp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]
2022-05-15 Excel sheet with MCU timing and power estimates
    [dot_calcs.xlsx]
2022-05-15 col 5 not working for some reason
    [single_pixel.ino]
2022-06-12 arduino files
